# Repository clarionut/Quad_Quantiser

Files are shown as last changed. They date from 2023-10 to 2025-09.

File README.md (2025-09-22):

# Quad_Quantiser
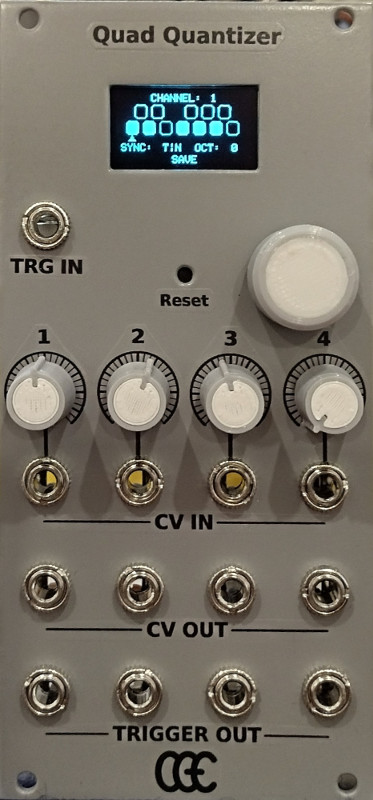
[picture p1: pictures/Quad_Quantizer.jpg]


The original inspiration for this project came from the [Dual Quantizer by Hagiwo](https://note.com/solder_state/n/nb8b9a2f212a2), in particular the use of an RP2040 microcontroller and the general style of the OLED display / rotary encoder user interface. There the resemblance pretty much ends.

This project uses a WaveShare RP2040 Zero board as the processor, a MAX5715 12-bit 4-channel SPI DAC buffered and amplified to give a 5-octave output range on each of the four channels, plus a 24LC04 I2C EEPROM to allow the configuration to be saved. Both cores of the RP2040 are used with core 0 handling the analogue inputs, quantisation and output to the MAX5715, while core 1 handles the rotary encoder / 0.96" I2C OLED screen user interface and also the EEPROM.

There is a trigger input (common to all channels) plus CV and trigger outputs for each individual channel. The trigger input is monitored by an interrupt rather than by polling, so fast triggers should be acceptable. The channels can be independently configured to change the CV output and generate a trigger when:
- a trigger is received even if the quantisation is unchanged (TRIG)
- the quantisation of an input changes (NOTE)
- a trigger is received _and_ the quantisation has changed (T&&N)
- a trigger is received _or_ the quantisation changes (T||N)

The code is intended for use in the Arduino IDE (v 2.x) using the Waveshare RP2040 Zero core. RP2040_Quantizer6.ino and MAX5715.h should both be in the sketch folder.

The Kicad schematic includes custom symbols and footprints for the RP2040 Zero and for the MAX5715. The PCB layout is for a board to be mounted on brackets perpendicular to the front panel, and also includes custom footprints for the RP2040, MAX5715 and the power connector. I've also included a STEP file model of the RP2040 board for use with the Kicad 3D viewer. Note that the WaveShare Rp2040 Zero board does not have a reset connection broken out - I soldered a very thin wire from the RESET pad on the main PCB to one of the pads on the RP2040 Zero's Reset switch

At present the quantisation is limited to the conventional western 12-semitone scale. One obvious extension is to include less conventional scales - e.g. quarter tone or Bohlen-Pierce.

This design and its associated software are published under the Creative Commons Attribution-ShareAlike 4.0 International (CC BY-SA) 4.0 Deed.

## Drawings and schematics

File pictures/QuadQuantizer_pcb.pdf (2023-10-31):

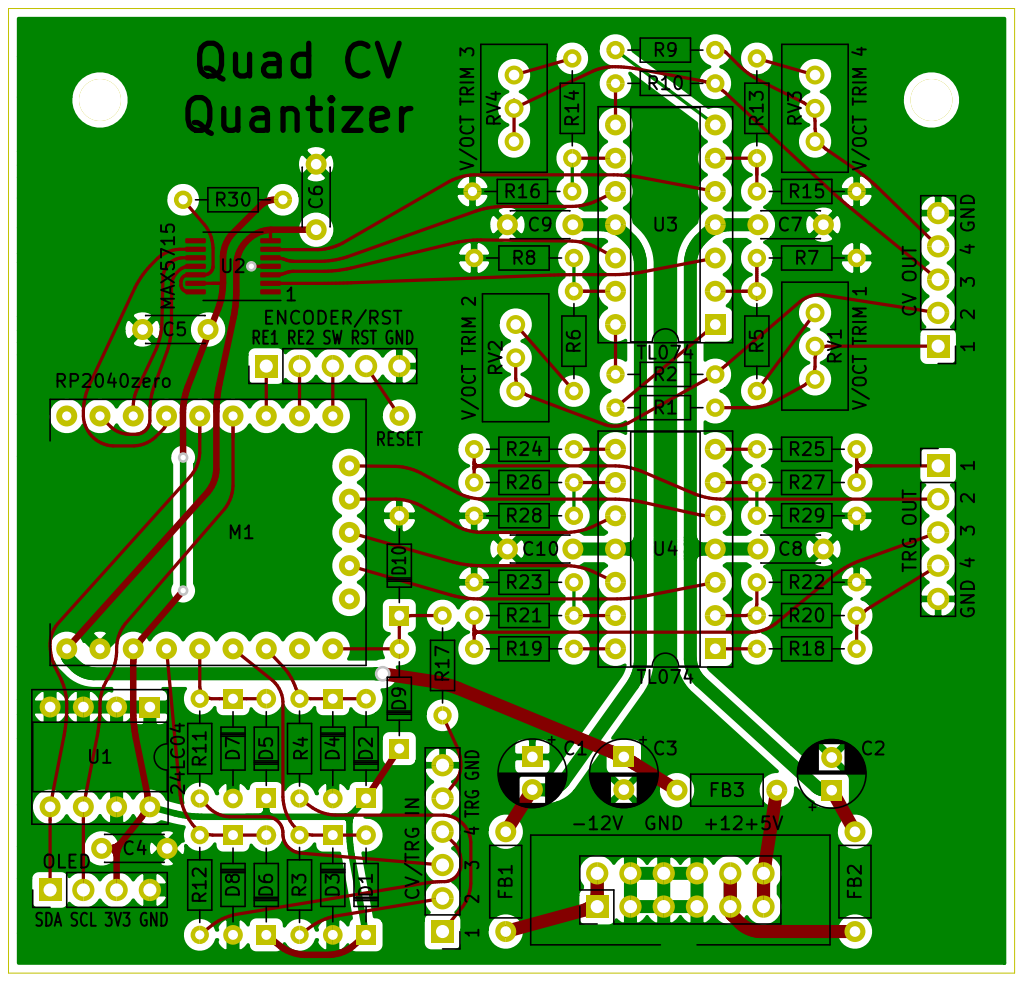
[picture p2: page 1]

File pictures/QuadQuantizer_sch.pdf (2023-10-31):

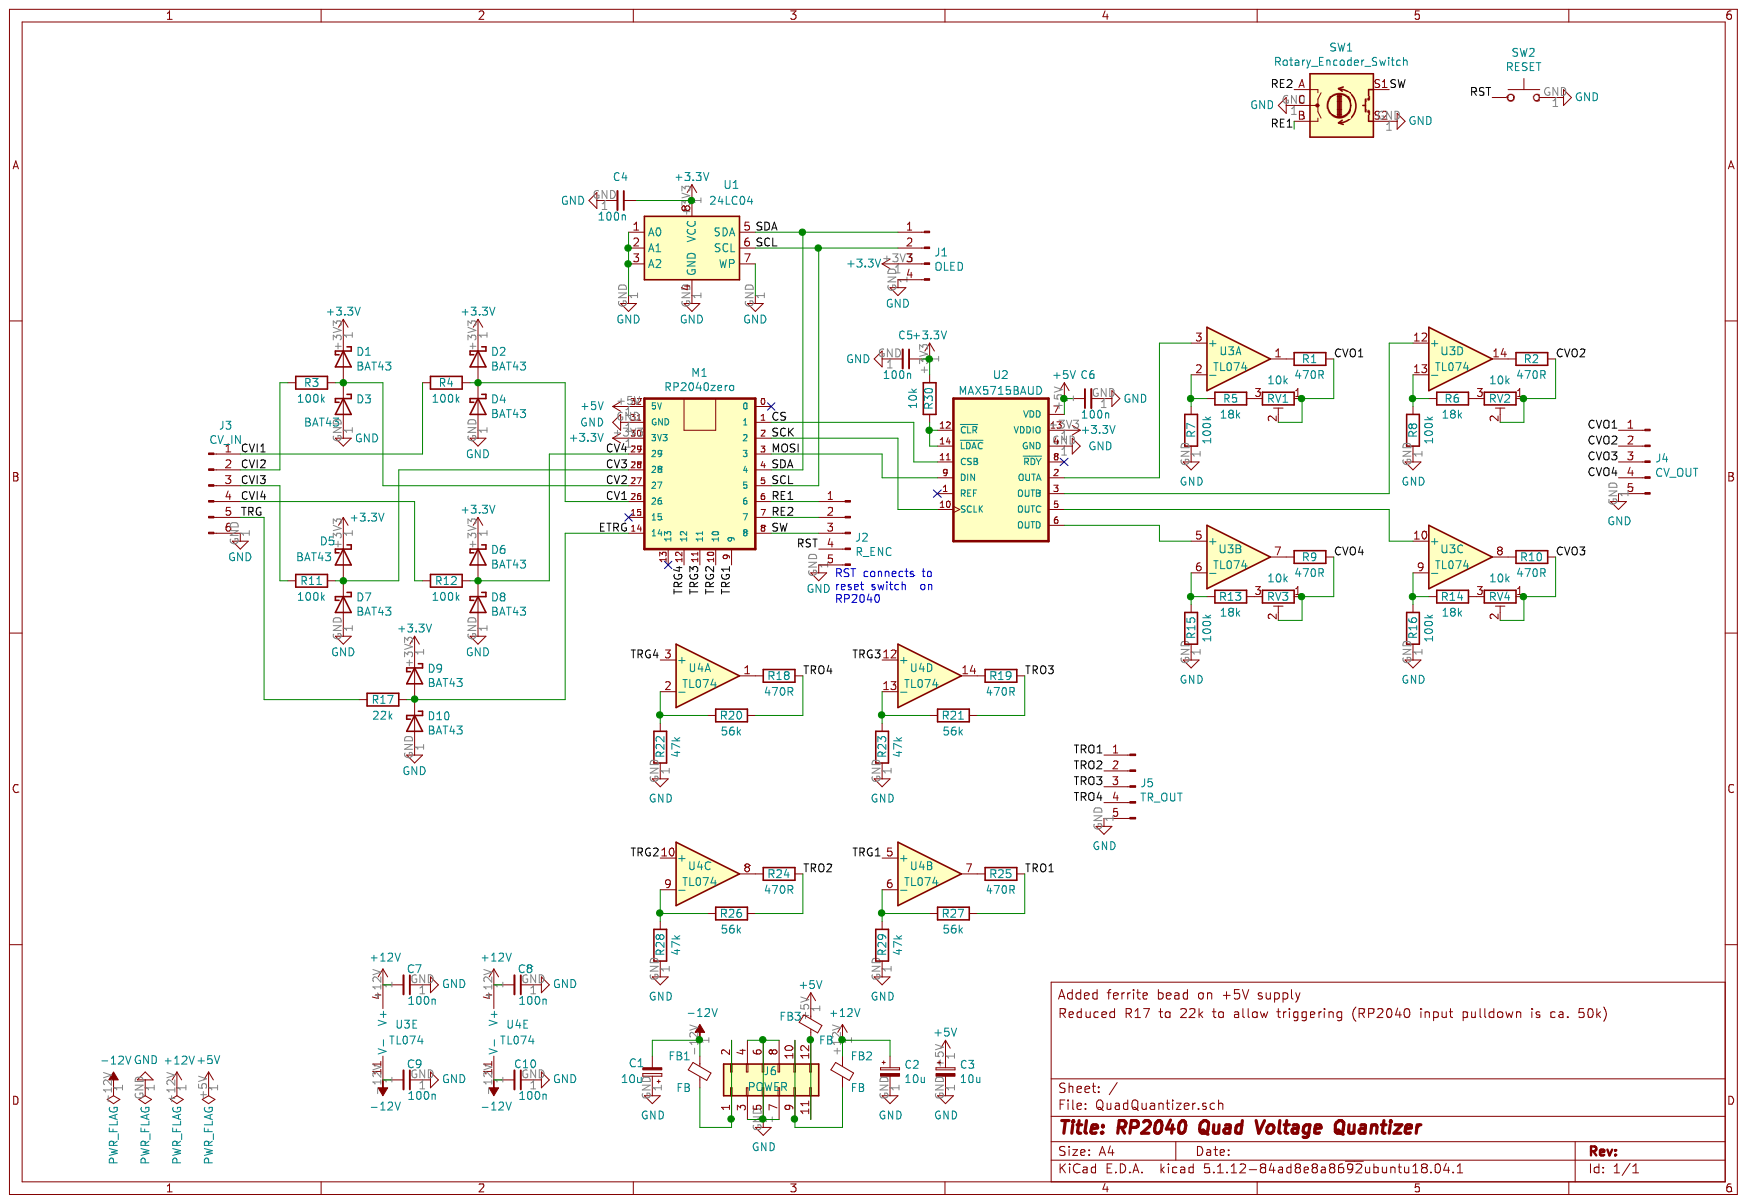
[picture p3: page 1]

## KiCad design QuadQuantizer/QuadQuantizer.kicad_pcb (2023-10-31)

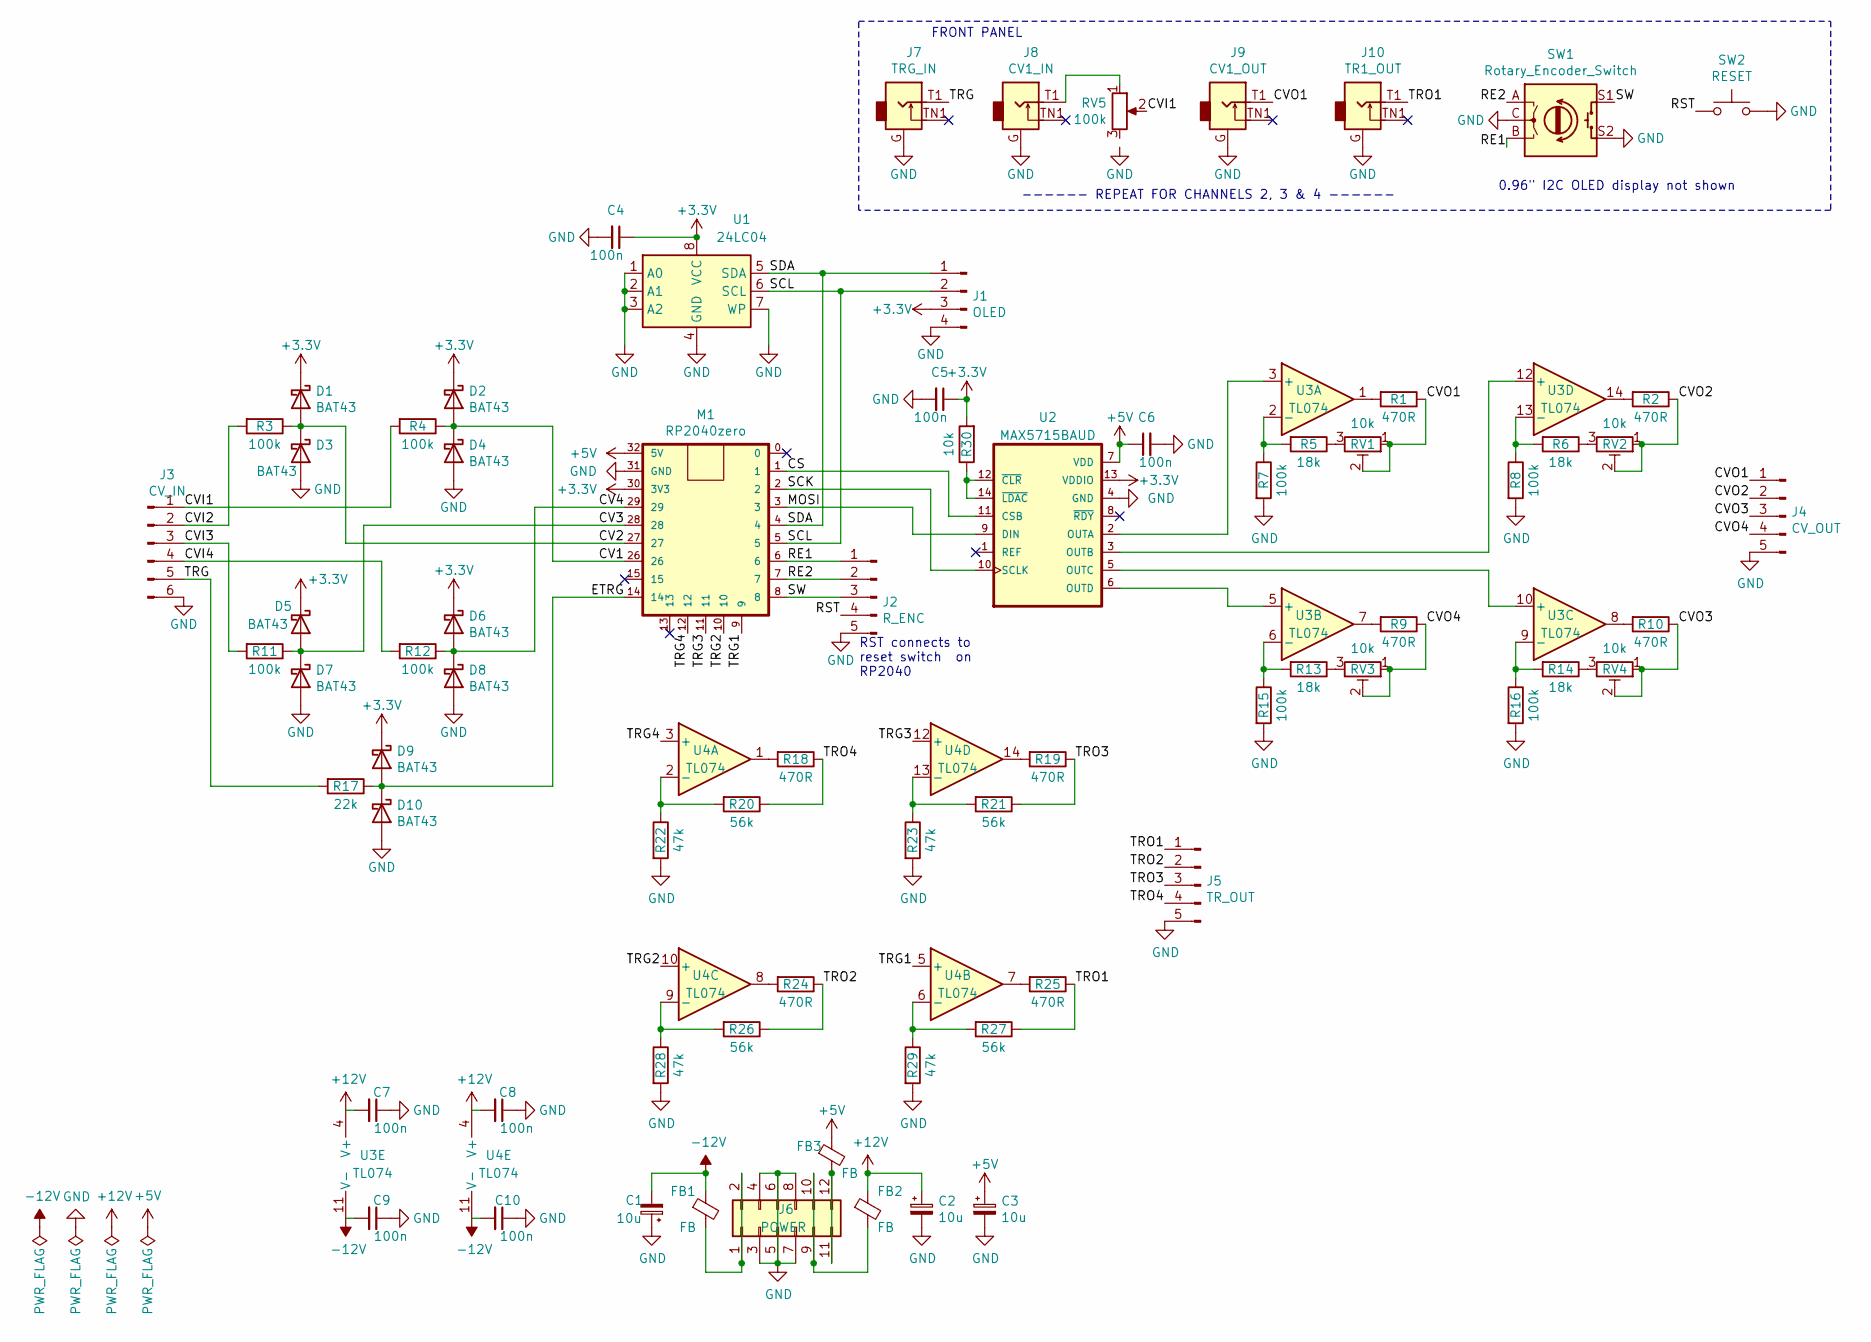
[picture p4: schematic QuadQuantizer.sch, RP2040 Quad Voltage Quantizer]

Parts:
C1, C2, C3: 10u; CP_Radial_D5.0mm_P2.50mm
C4, C5, C6, C7, C8, C9, C10: 100n; C_Disc_D4.3mm_W1.9mm_P5.00mm
D1, D2, D3, D4, D5, D6, D7, D8, D9, D10: BAT43; D_DO-34_SOD68_P7.62mm_Horizontal
FB1, FB2, FB3: FB; L_Axial_L5.3mm_D2.2mm_P7.62mm_Horizontal_Vishay_IM-1
J1: OLED; PinHeader_1x04_P2.54mm_Vertical
J2: R_ENC; PinHeader_1x05_P2.54mm_Vertical
J3: CV_IN; PinHeader_1x06_P2.54mm_Vertical
J4: CV_OUT; PinHeader_1x05_P2.54mm_Vertical
J5: TR_OUT; PinHeader_1x05_P2.54mm_Vertical
J6: POWER; Power_2x06
J7: TRG_IN
J8: CV1_IN
J9: CV1_OUT
J10: TR1_OUT
M1: RP2040zero; RP2040zeroA
R1, R2, R9, R10, R18, R19, R24, R25: 470R; R_Axial_DIN0204_L3.6mm_D1.6mm_P7.62mm_Horizontal
R3, R4, R7, R8, R11, R12, R15, R16: 100k; R_Axial_DIN0204_L3.6mm_D1.6mm_P7.62mm_Horizontal
R5, R6, R13, R14: 18k; R_Axial_DIN0204_L3.6mm_D1.6mm_P7.62mm_Horizontal
R17: 22k; R_Axial_DIN0204_L3.6mm_D1.6mm_P7.62mm_Horizontal
R20, R21, R26, R27: 56k; R_Axial_DIN0204_L3.6mm_D1.6mm_P7.62mm_Horizontal
R22, R23, R28, R29: 47k; R_Axial_DIN0204_L3.6mm_D1.6mm_P7.62mm_Horizontal
R30: 10k; R_Axial_DIN0204_L3.6mm_D1.6mm_P7.62mm_Horizontal
RV1, RV2, RV3, RV4: 10k; Potentiometer_Bourns_3296W_Vertical
RV5: 100k
SW1: Rotary_Encoder_Switch
SW2: RESET
U1: 24LC04; DIP-8_W7.62mm_Socket
U2: MAX5715BAUD; SOP-14-1EP_4.4x5mm_P0.65mm_EP3.4x5mm
U3, U4: TL074; DIP-14_W7.62mm_Socket

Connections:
+3V3: C4.1, C5.1, D1.1 (K), D2.1 (K), D5.1 (K), D6.1 (K), D9.1 (K), J1.3, M1.30 (3V3), R30.2, U1.8 (VCC), U2.13 (VDDIO)
+5V: C3.1, C6.1, FB3.1, M1.32 (5V), U2.7 (VDD)
+12V: C2.1, C7.2, C8.2, FB2.1, U3.4 (V+), U4.4 (V+)
-12V: C1.2, C9.2, C10.2, FB1.1, U3.11 (V-), U4.11 (V-)
/CS: M1.1, U2.11 (CSB)
/CV1: D2.2 (A), D4.1 (K), M1.26, R4.1
/CV2: D1.2 (A), D3.1 (K), M1.27, R3.1
/CV3: D5.2 (A), D7.1 (K), M1.28, R11.1
/CV4: D6.2 (A), D8.1 (K), M1.29, R12.1
/CVI1: J3.1, R4.2, RV5.2
/CVI2: J3.2, R3.2
/CVI3: J3.3, R11.2
/CVI4: J3.4, R12.2
/CVO1: J4.1, J9.T1, R1.1, RV1.1, RV1.2
/CVO2: J4.2, R2.1, RV2.1, RV2.2
/CVO3: J4.3, R10.1, RV4.1, RV4.2
/CVO4: J4.4, R9.1, RV3.1, RV3.2
/ETRG: D9.2 (A), D10.1 (K), M1.14, R17.1
/MOSI: M1.3, U2.9 (DIN)
/RE1: J2.1, M1.6, SW1.B
/RE2: J2.2, M1.7, SW1.A
/RST: J2.4, SW2.1; also elsewhere on the board
/SCK: M1.2, U2.10 (SCLK)
/SCL: J1.2, M1.5, U1.6 (SCL)
/SDA: J1.1, M1.4, U1.5 (SDA)
/SW: J2.3, M1.8, SW1.S1
/TRG: J3.5, J7.T1, R17.2
/TRG1: M1.9, U4.5 (+)
/TRG2: M1.10, U4.10 (+)
/TRG3: M1.11, U4.12 (+)
/TRG4: M1.12, U4.3 (+)
/TRO1: J5.1, J10.T1, R25.1, R27.1
/TRO2: J5.2, R24.1, R26.1
/TRO3: J5.3, R19.1, R21.1
/TRO4: J5.4, R18.1, R20.1
GND: C1.1, C2.2, C3.2, C4.2, C5.2, C6.2, C7.1, C8.1, C9.1, C10.1, D3.2 (A), D4.2 (A), D7.2 (A), D8.2 (A), D10.2 (A), J1.4, J2.5, J3.6, J4.5, J5.5, J6.3, J6.4, J6.5, J6.6, J6.7, J6.8, J7.G, J8.G, J9.G, J10.G, M1.31 (GND), R7.2, R8.2, R15.2, R16.2, R22.2, R23.2, R28.2, R29.2, SW1.C, SW1.S2, SW2.2, U1.1 (A0), U1.2 (A1), U1.3 (A2), U1.4 (GND), U1.7 (WP), U2.4 (GND)
unnamed: FB1.2, J6.1, J6.2
unnamed: FB2.2, J6.9, J6.10
unnamed: FB3.2, J6.11, J6.12
unnamed: J8.T1, RV5.1
unnamed: R1.2, U3.1
unnamed: R2.2, U3.14
unnamed: R5.1, RV1.3
unnamed: R5.2, R7.1, U3.2 (-)
unnamed: R6.1, RV2.3
unnamed: R6.2, R8.1, U3.13 (-)
unnamed: R9.2, U3.7
unnamed: R10.2, U3.8
unnamed: R13.1, RV3.3
unnamed: R13.2, R15.1, U3.6 (-)
unnamed: R14.1, RV4.3
unnamed: R14.2, R16.1, U3.9 (-)
unnamed: R18.2, U4.1
unnamed: R19.2, U4.14
unnamed: R20.2, R22.1, U4.2 (-)
unnamed: R21.2, R23.1, U4.13 (-)
unnamed: R24.2, U4.8
unnamed: R25.2, U4.7
unnamed: R26.2, R28.1, U4.9 (-)
unnamed: R27.2, R29.1, U4.6 (-)
unnamed: R30.1, U2.12 (~CLR), U2.14 (~LDAC)
unnamed: U2.2 (OUTA), U3.3 (+)
unnamed: U2.3 (OUTB), U3.12 (+)
unnamed: U2.5 (OUTC), U3.10 (+)
unnamed: U2.6 (OUTD), U3.5 (+)

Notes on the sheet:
RST connects to reset switch on RP2040
------ REPEAT FOR CHANNELS 2, 3 & 4 ------
0.96" I2C OLED display not shown
FRONT PANEL

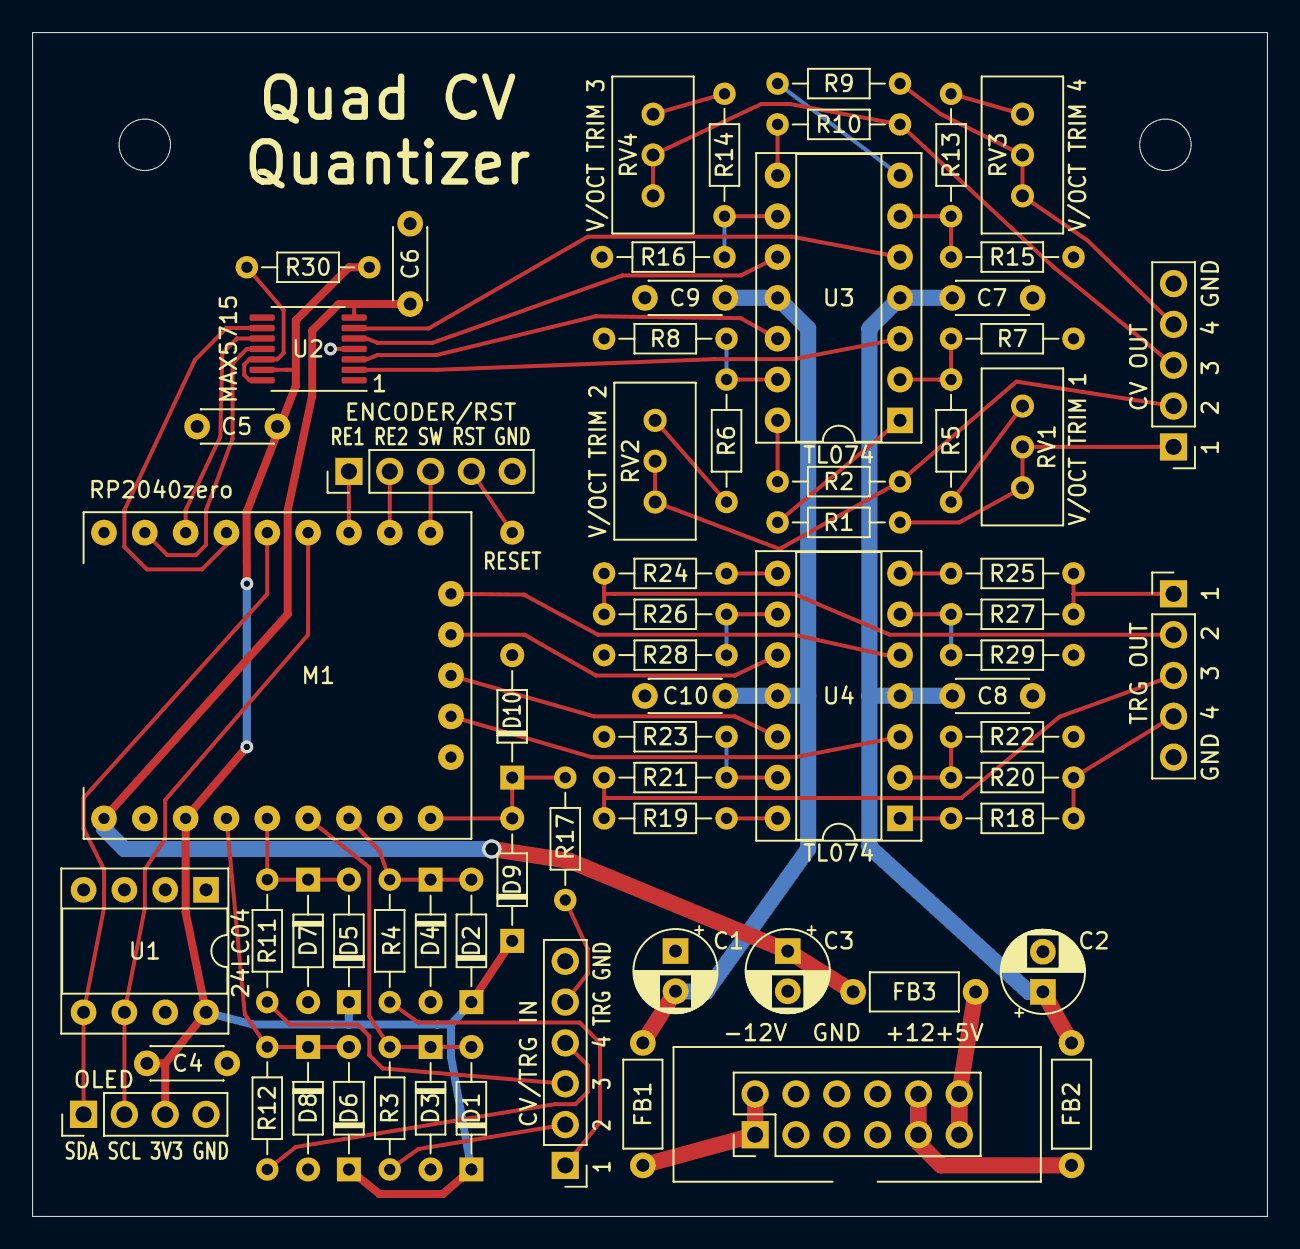
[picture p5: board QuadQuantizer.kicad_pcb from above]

Board: 2 copper layers, 76.8 x 73.7 mm, 69 parts (0 on the bottom side), 64 nets.

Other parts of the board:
RST: RST; TestPoint_THTPad_D1.5mm_Drill0.7mm

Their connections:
/RST: RST.1; also elsewhere on the board

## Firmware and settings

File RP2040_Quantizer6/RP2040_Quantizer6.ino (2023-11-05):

/*
        RP2040 zero based 4 channel voltage quantizer

        Inspired by Hagiwo's Dual Quantizer - https://note.com/solder_state/n/nb8b9a2f212a2

        Details of this implementation:
        - a 5 octave range on each channel using a MAX5715 quad SPI DAC
          for the 4 output channels. Needs a pullup on both !CLR and !LDAC
        - a 24LC04 I2C EEPROM for storage of settings
        - op-amp buffered outputs with V/oct trimmers
        - four trigger outputs via op-amp buffers
        - quantization & SPI processes run on core 0, UI (encoder) and I2C
          processes (screen, EEPROM) on core 1

        Compile using the Waveshare RP2040 Zero core
 */
#include <Wire.h>
#include <I2C_eeprom.h>
#include <SPI.h>
#include <Adafruit_SSD1306.h>
#include <Adafruit_GFX.h>
#include <pio_encoder.h>
#include "MAX5715.h"

#define ENC_SW 8
#define EXT_TRG 14
#define CVBASE 26
#define TRGBASE 9

#define DEBUGX

// 4 or 5 octaves
#define OCTAVES 5

static const uint8_t numSteps = OCTAVES * 12 + 1;

Adafruit_SSD1306 display(128, 64, &Wire, -1);

// rotary encoder setup
PioEncoder myEnc(6); // also pin 7!
int oldPosition = 0;
int newPosition = 0;
int item = 1;

uint8_t encSw = 1;
uint8_t oldEncSw = 1;
//uint8_t CLK_in = 0;
//uint8_t old_CLK_in = 0;
uint8_t newTrig = 0;

int cvIn[4], oldCvIn[4];
int cvOut[4], oldCvOut[4] = {9999};
uint8_t trigAct[4] = {0};
unsigned long trigMicros[4]; // timers for the triggers
unsigned long screenMillis;
uint8_t screenSave = 0;

// Y positions of white and black notes
int16_t yPos[] = {25, 10, 25, 10, 25, 25, 10, 25, 10, 25, 10, 25};

// note status; 1 = enabled, 0 = disabled
uint8_t note[4][12];

// configure EEPROM
I2C_eeprom eeprom(0x50, I2C_DEVICESIZE_24LC04);

struct configStruct {
  uint16_t note_str[4];  // ch1-4 enabled notes
  uint8_t sync;          // 2 bits each 0 = TRIG, 1 = NOTE, 2 = TRIG & NOTE, 3 = TRIG | NOTE
  uint16_t oct;          // octave offsets (3 bits each)
};
configStruct config;

int8_t sync[4] = {0}; // sync with: 0, trig; 1, note changed; 2, trig AND note; 3, trig OR note
char syncType[][5] = {"TRIG", "NOTE", "T&&N", "T||N"};
int8_t oct[4] = {0}; // octave shift
int8_t chnl = 0, mode = 0;

// CV setting
int cvQuant[4][numSteps]; // input quantization steps
uint8_t qntSteps[4];
int semitone[numSteps];
uint8_t noteChanged;

// should display be refreshed? (1 = yes, 0 = no)
uint8_t oledRefresh = 1;

// DAC commands
uint8_t codeLoad[4] = {CODEA_LOADA, CODEB_LOADB, CODEC_LOADC, CODED_LOADD};

void setup() {
  // run the quantization code on core 0
#ifdef DEBUG
  Serial.begin(115200);
  while (!Serial);
#endif
  // set up trigger out, clock in and analogue pins
  for (uint8_t i = 0; i < 4; i++) {
    pinMode(TRGBASE + i, OUTPUT);
    digitalWrite(TRGBASE + i, 0);
  }
  pinMode(EXT_TRG, INPUT_PULLDOWN); // CLK in
  attachInterrupt(digitalPinToInterrupt(EXT_TRG), trgIn, RISING);
  analogReadResolution(12);
  analogRead(CVBASE);

  // Initialise SPI
  SPI.setRX(0);
  SPI.setCS(1);
  SPI.setSCK(2);
  SPI.setTX(3);
  SPI.begin(1);

  // Set normal power mode for all DACs, internal ref. to 4.096V, all DACS to 0V
  write5715(PWR_NORM, 0x0F00);
  write5715(REFINT41, 0x0000);
  write5715(CODEALL_LOADALL, 0x0000);

  // Calculate DAC values for each semitone
  for (uint8_t i = 0; i < numSteps; i++) {
    semitone[i] = (int) (0.5 + 4095.0 / (OCTAVES * 12) * (float) i);
  }

  // Wait (using a blocking pop) until the other core has read the EEPROM
  rp2040.fifo.pop();

  // Initial quantizer setting
  for (uint8_t i = 0; i < 4; i++) {
    uint8_t k = 0;
    for (uint8_t j = 0; j < numSteps; j++) {
      if (note[i][j % 12]) {
        cvQuant[i][k] = semitone[j];
        k++;
      }
    }
    qntSteps[i] = k;
  }
  noteChanged = 0;
}

void setup1() {
  // Run the I2C (screen, EEPROM) & rotary encoder code on core 1

  Wire.begin();

  // Set up the encoder
  myEnc.begin();
  pinMode(ENC_SW, INPUT_PULLUP);

  // Initialize OLED
  display.begin(SSD1306_SWITCHCAPVCC, 0x3C);
  display.clearDisplay();

  // Read stored data
  eeprom.begin();
  if (eeprom.isConnected()) {
    eeprom.readBlock(0, (uint8_t *) &config, sizeof(config));
  } else {
    // No EEPROM so set defaults
    for (uint8_t i = 0; i < 4; i++) {
      config.note_str[i] = 0;
    }
    config.sync = 0;
    // all octave shifts set to 0
    config.oct = 0b010010010010;
  }
  for (uint8_t i = 0; i < 4; i++) {
    // active / inactive notes
    for (uint8_t j = 0; j < 12; j++) {
      note[i][j] = (config.note_str[i] >> j) & 1U;
    }
    // sync mode
    sync[i] = (config.sync >> (i * 2)) & 0x03;
    // octave offset
    oct[i] = (config.oct >> (i * 3)) & 0x07;
  }
  // Tell the other core that EEPROM data has been read
  rp2040.fifo.push_nb(1);

  screenMillis = millis();
}

void loop() {
  // Quantize input CVs and handle triggers according to the config settings
  //old_CLK_in = CLK_in;

  // Turn off any expired triggers
  for (uint8_t i = 0; i < 4; i++) {
    if (trigAct[i] && (micros() - trigMicros[i]) > 5000) {
      digitalWrite(TRGBASE + i, 0);
      trigAct[i] = 0;
    }
  }

  // Read input CVs and quantize
  for (uint8_t i = 0; i < 4; i++) {
    cvIn[i] = analogRead(CVBASE + i);
    if (qntSteps[i]) {
      // At least one quantisation note selected
      cvIn[i] &= 0xFFFC; // clear the lowest 2 bits to de-jitter
      // Allow settling time for the next ADC reading
      if (i < 3)
        analogRead(CVBASE + i + 1);
      else
        analogRead(CVBASE);
      // ADC anti-jitter - ignore small changes
      if (abs(oldCvIn[i] - cvIn[i]) >= 20) {
        for (uint8_t j = 0; j < qntSteps[i] - 1; j++) {
          // Quantize each channel
          if (cvIn[i] < cvQuant[i][j + 1]) {
            // The input CV is in the current quantization interval, so find the nearer note
            if ((cvIn[i] - cvQuant[i][j]) <= (cvQuant[i][j+1] - cvIn[i])) {
              // Closer to the lower note
              cvOut[i] = cvQuant[i][j] + (oct[i] - 2) * 1000;
            } else {
              // Closer to the upper note
              cvOut[i] = cvQuant[i][j+1] + (oct[i] - 2) * 1000;
            }
            break;
          }
        }
      }
    } else {
      // No quantisation specified, so output unchanged apart from octave shift
      cvOut[i] = cvIn[i] + (oct[i] - 2) * 1000;
    }
    while (cvOut[i] < 0)    cvOut[i] += 1000;
    while (cvOut[i] > 4095) cvOut[i] -= 1000;
  }

  // Output quantized CVs and triggers if required
  //CLK_in = digitalRead(EXT_TRG);
  //if (CLK_in == 1 && old_CLK_in == 0) newTrig = 1;

  for (uint8_t i = 0; i < 4; i++) {
    // Output CV amd trigger if criteria are met
    if ((3 == sync[i] && (newTrig || cvOut[i] != oldCvOut[i])) ||  // T|N
        (2 == sync[i] && newTrig && cvOut[i] != oldCvOut[i]) ||    // T&N
        (1 == sync[i] && cvOut[i] != oldCvOut[i]) ||               // NOTE
        (0 == sync[i] && newTrig)) {                               // TRIG
      // CV
      write5715(CODEA_LOADA + i, cvOut[i]);
      oldCvIn[i] = cvIn[i];
      oldCvOut[i] = cvOut[i];
      // Trigger only for quantised output or active trigger
      if (newTrig || qntSteps[i]) {
        digitalWrite(TRGBASE + i, 1);
        trigMicros[i] = micros();
        trigAct[i] = 1;
      }
    }
  }
  newTrig = 0;
}

void loop1() {
    // Start screensaver after 60 seconds
  if (!screenSave && (millis() - screenMillis > 60000)) {
    screenSave = 1;
    display.clearDisplay();
    display.display();
  }
  // Process rotary encoder input
  oldEncSw = encSw;
  newPosition = myEnc.getCount();
  // Encoder has 4 steps per detent
  if (((newPosition - 3) / 4  > oldPosition / 4) || ((newPosition + 3) / 4  < oldPosition / 4)) {
    int8_t inc = 0;
    if ((newPosition - 3) / 4  > oldPosition / 4)
      inc = -1;
    else if ((newPosition + 3) / 4  < oldPosition / 4)
      inc = +1;
    oledRefresh = 1;
    oldPosition = newPosition;
    if (screenSave) {
      screenSave = 0;
    } else if (0 == mode) {
     item += inc;
      if (-1 == item) item = 15;
      item %= 16;
    } else {
      switch (item) {
       case 0:
        chnl += inc;
        if (chnl < 0) chnl = 3;
        chnl %= 4;
        break;
       case 13:
        sync[chnl] += inc;
        if (sync[chnl] < 0) sync[chnl] = 3;
        sync[chnl] %= 4;
        break;
       case 14:
        oct[chnl] += inc;
        if (oct[chnl] < 0) oct[chnl] = 4;
        oct[chnl] %= 5;
        break;
      }
    }
    screenMillis = millis();
  }
  item = constrain(item, 0, 15);

  // Process push switch input
  encSw = digitalRead(ENC_SW);
  if (encSw && !oldEncSw) {
    oledRefresh = 1;
    if (screenSave) {
      screenSave = 0;
    } else if (0 == mode) {
      if (0 == item) {
        mode = 1;
      } else if (item <= 12 && item >= 1) {
        // note selection
        note[chnl][item - 1] = !note[chnl][item - 1];
        noteChanged = 1;

      } else if ((13 == item) || (14 == item)) {
        // sync or oct setting
        mode = 1;

      } else if (15 == item) {
        save();
      }

      // Update the active note selection
      if (noteChanged) {
        for (uint8_t i = 0; i < 4; i++) {
          uint8_t k = 0;
          for (uint8_t j = 0; j < numSteps; j++) {
            if (note[i][j % 12] == 1) {
              cvQuant[i][k] = semitone[j];
              k++;
            }
          }
          qntSteps[i] = k;
        }
        noteChanged = 0;
      }

    } else {
      mode = 0;
    }
    screenMillis = millis();
  }
  // Update display if necessary
  if (oledRefresh == 1) {
    OLED_display();
    oledRefresh = 0;
  }
}

void OLED_display() {
  display.clearDisplay();
  display.setTextSize(1);
  display.setTextColor(WHITE);
  // Channel number
  display.setCursor(34, 0);
  display.print("CHANNEL:");
  display.setCursor(91, 0);
  display.print(chnl + 1);
  // Notes
  int xPos = 10;
  for (uint8_t i = 0; i < 12; i++) {
    drawNote(xPos, yPos[i], 12, 13, 3, WHITE, note[chnl][i]);
    // Skip non-existent black note between E & F
    xPos += (4 == i) ? 16 : 8;
  }
  // Config settings
  display.setCursor(5, 46);
  display.print("SYNC: ");
  display.setCursor(45, 46);
  display.print(syncType[sync[chnl]]);
  display.setCursor(64, 46);
  display.print("  OCT: ");
  display.setCursor(111, 46);
  display.print(oct[chnl] - 2);
  display.setCursor(54, 57);
  display.print("SAVE");
  // Draw pointer for current item
  if (0 == item) {
    // Channel
    if (1 == mode)
      // Change channel
      display.drawCircle(85, 3, 2, WHITE);
    else
      drawPointer(82, 0, 82, 6, 88, 3, WHITE, 0);
  } else if (item <= 5) {
    // First five notes
    drawPointer(7 + item * 8, 38, 4 + item * 8, 43, 10 + item * 8, 43, WHITE, 1);
  } else if (item >= 6 && item <= 12) {
    // Remainder of notes
    drawPointer(15 + item * 8, 38, 12 + item * 8, 43, 18 + item * 8, 43, WHITE, 1);
  } else if (13 == item) {
    // Sync
    if (1 == mode) {
      // Change sync mode
      display.drawCircle(38, 49, 2, WHITE);
    } else {
      drawPointer(35, 46, 35, 52, 41, 49, WHITE, 0);
    }
  } else if (14 == item) {
    // Octave
    if (1 == mode) {
      // Change octave offset
      display.drawCircle(104, 49, 2, WHITE);
    } else {
      drawPointer(101, 46, 101, 52, 107, 49, WHITE, 0);
    }
  } else if (15 == item) {
    // Save
    drawPointer(44, 57, 44, 63, 50, 60, WHITE, 1);
  }
  display.display();
}

void save() {
  // Save settings data to EEPROM
  display.clearDisplay();
  display.setTextColor(BLACK, WHITE);
  if (eeprom.isConnected()) {
    config.sync = 0;
    config.oct = 0;
    for (uint8_t i = 0; i < 4; i++) {
      // Note on/off settings
      for (uint8_t j = 0; j < 12; j++) {
        if (note[i][j])
          config.note_str[i] |= (1U << j);
        else
          config.note_str[i] &= ~(1U << j);
      }
      // Trigger sync setting
      config.sync <<= 2;
      config.sync |= sync[3 - i];
      // Octave offset
      config.oct <<= 3;
      config.oct |= oct[3 - i];
    }
    eeprom.writeBlock(0, (uint8_t *) &config, sizeof(config));
    display.setCursor(38, 57);
    display.print(" SAVED ");
  } else {
    display.setCursor(24, 57);
    display.print(" NO EEPROM ");
  }
  // Show message on completion
  display.display();
  delay(1000);
}

void write5715(uint8_t cmd, uint16_t data) {
  // Send values to the MAX5715
  // N.B. The data values written to the MAX5715 must match the description in the data sheet
  // Do the required bit shift here
  data <<= 4;
  uint8_t tmp[3];
  tmp[0] = cmd;
  tmp[1] = (data & 0xFF00) >> 8;
  tmp[2] = (data & 0x000F);

  SPI.beginTransaction(SPISettings(4000000, MSBFIRST, SPI_MODE1));
  SPI.transfer(&tmp, nullptr, 3);
  SPI.endTransaction();

  delayMicroseconds(1);
}

void drawNote(int16_t x, int16_t y, int16_t w, int16_t h, int16_t r, uint16_t c, uint8_t f) {
  // Draw note rectangle; fill type specified by parameter f
  if (f)
    display.fillRoundRect(x, y, w, h, r, c);
  else
    display.drawRoundRect(x, y, w, h, r, c);
}

void drawPointer(int16_t x0, int16_t y0, int16_t x1, int16_t y1, int16_t x2, int16_t y2, int16_t c, uint8_t f) {
  // Draw pointer, fill type specified by parameter f
  // Filled pointers => click for immediate action
  // Empty pointers  => click to enable rotary encoder for selection, click again to finish
  if (f)
    display.fillTriangle(x0, y0, x1, y1, x2, y2, c);
  else
    display.drawTriangle(x0, y0, x1, y1, x2, y2, c);
}

void trgIn() {
  newTrig = 1;
}
